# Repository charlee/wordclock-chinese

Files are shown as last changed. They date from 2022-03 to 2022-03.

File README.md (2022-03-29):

Chinese Word Clock
======================

[中文版](#汉字文字钟)

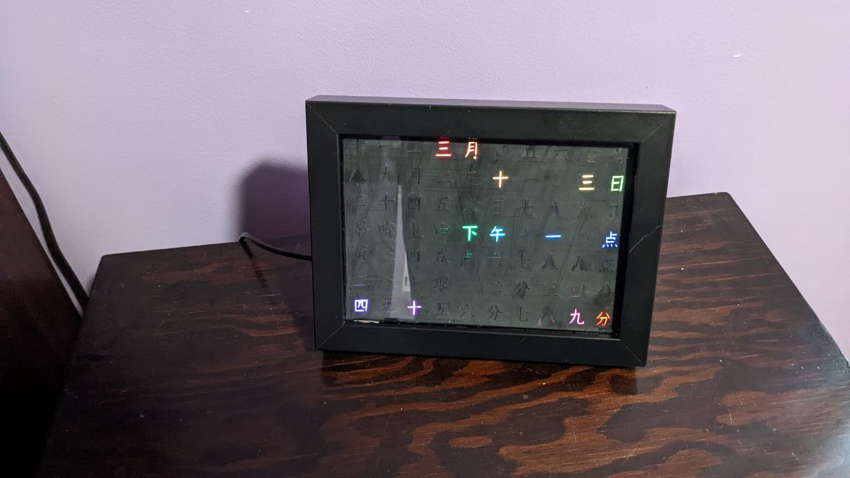
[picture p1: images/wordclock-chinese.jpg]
Chinese Word Clock


Inspired by the famous [Word Clock](https://www.instructables.com/Wordclock/),
this project created a word clock that consists of Chinese characters.
Driven by an ESP8266, this clock synchronize time from NTP servers automatically.

## Hardware

The clock itself is a 7x10 LED matrix consists of 70 WS2812b RGB LEDs,
cut from an LED strip. The microcontroller is an ESP8266 DevKit,
which provides Micro-USB interface used to power the ESP8266 and the LEDs.

### Power

WS2812b RGB consumes a lot of power. When displaying white color in full brightness,
it consumes about 60mA at 5V (20mA per R, G, B color). 
In the worst case, there are 16 LEDs being turned on (e.g. "十二月二十四日晚上十一点五十六分"),
which consumes 60mA * 16 = 960mA. 

Also, according to [the datasheet of ESP8266](https://www.espressif.com/sites/default/files/documentation/0a-esp8266ex_datasheet_en.pdf), it consumes about 170mA when using WiFi.

So the total current is about 1.2A. Therefore, a USB power adapter at least 1.5A is required.

Also note that 1.2A goes way beyond the 500mA limit that computer USB ports could provide.
When debugging / developing programs on the computer, make sure to use a small brightness.

### Frame and Case

The frame is an [IDEA RIBBA 13cm x 18cm Picture Frame](https://www.ikea.com/ca/en/p/ribba-frame-white-70378414).
This frame is inexpensive, and is thick enough to hide electronic components inside. It is a good choice for similar electronic projects.

In the [STL](STL/) folder I provided the STL files used in these project.

## Development

The program is written with Arduino. 

The whole program consists of the following parts:

- `ChineseWordMatrix.*`: convert timestamps to LED indicies.
- `EEPROMConfig.*`, `ESP8266AutoConfig.*`, `WiFiConfig.*`: provides the WiFi management functionality.
- `Animation.*`: implements the fade in/fade out/breathing animations.

汉字文字钟
============

本项目是一个汉字版本的文字钟，通过钟面上的汉字来显示时间。创意来自[Word Clock](https://www.instructables.com/Wordclock/)。
微控制器为ESP8266，因此设备支持WiFi，并且可以自动从NTP服务器同步时间。

## 硬件

钟面本身由70个 WS2812b RGB LED组成。LED来自一条RGB LED灯带。微控制器为一块ESP8266开发板，
可以通过Micro-USB为ESP8266和LED供电。

### 电源

WS2812b RGB LED本身会消耗很大电力。在以最大亮度显示白色时，一颗RGB大约产生60mA的电流（红黄蓝每种颜色各20mA）。
在最坏的情况下，会有16个LED同时亮起（例如“十二月十二四日晚上十一点五十六分”），此时产生的电流为 60mA * 16 = 960mA。

另外，根据[ESP8266的数据手册](https://www.espressif.com/sites/default/files/documentation/0a-esp8266ex_datasheet_en.pdf)，在使用WiFi时，
ESP8266会产生大约170mA的电流。

总电流约为1.2A。因此，需要使用至少1.5A的USB适配器来供电。

另外，1.2A已远远超过了电脑的USB接口能提供的500mA限制。因此在开发或调试时，务必将brightness设为一个较小的值。

### 框体和外壳

框体采用的是[宜家的RIBBA 15cm x 18cm 相框](https://www.ikea.com/ca/en/p/ribba-frame-white-70378414).
这款相框非常便宜，而且足够厚，内部可以容纳许多电子元件，非常适合类似的项目。

[STL](STL/)文件夹下提供了本项目用到的STL文件。

## 开发

程序基于Arduino。

整个程序由以下模块组成：

- `ChineseWordMatrix.*`：负责将时间戳转换成LED的序号。
- `EEPROMConfig.*`, `ESP8266AutoConfig.*`, `WiFiConfig.*`：负责WiFi管理和配置。
- `Animation.*`：用于产生渐入/渐出和呼吸效果的动画。

## License

Shield: [][cc-by-nc-sa]

This work is licensed under a
[Creative Commons Attribution-NonCommercial-ShareAlike 4.0 International License][cc-by-nc-sa].

[][cc-by-nc-sa]

[cc-by-nc-sa]: http://creativecommons.org/licenses/by-nc-sa/4.0/
[cc-by-nc-sa-image]: https://licensebuttons.net/l/by-nc-sa/4.0/88x31.png
[cc-by-nc-sa-shield]: https://img.shields.io/badge/License-CC%20BY--NC--SA%204.0-lightgrey.svg

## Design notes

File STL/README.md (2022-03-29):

STL Files
=====================

[中文版](STL文件)

This folder contains the STL files I used in this project.

- `mask.stl`: The mask with Chinese characters. I don't have a CNC carving machine so I printed it. Use a CNC to get a better result, if you have one.
  - When slicing, *flip the model* to make it facing down (to get a flat surface), then *rotate it 45 degree* (to avoid 45 degree printing marks).
  - Calibrate your flow rate to avoid any overextrusion. Overextrusion will fill the gap for the characters and lead to failure.
  - DO NOT use ironing.
  - Sand the surface with sandpapers. Use 400 => 600 => 1000 => 1500 grit to get a good result.
- `grid.stl`: The grid for blocking the LED lights.
- `case-bottom.stl` and `case-lid.stl`: The case for the ESP8266 Dev Kit.

STL文件
=========

本文件夹提供了项目中用到的STL文件。

- `mask.stl`：写有汉字的遮罩。这个遮罩用CNC雕刻机制作的效果最好，但我只有3D打印机，只能打印了。
  - 在切片前，将模型*翻转*至正面朝下（以获得平整的表面），并*旋转45度*（避免出现45度角的打印痕迹）。
  - 务必校准打印机的flow rate，避免过度挤出。过度挤出会填满汉字的缝隙，导致打印失败。
  - **不要使用ironing**。
  - 打印完毕后用砂纸打磨表面。建议采用400 => 600 => 1000 => 1500的顺序以获得较好的效果
- `grid.stl`：阻光用的格栅。
- `case-bottom.stl` 和 `case-lid.stl`：ESP8266开发板的外壳。

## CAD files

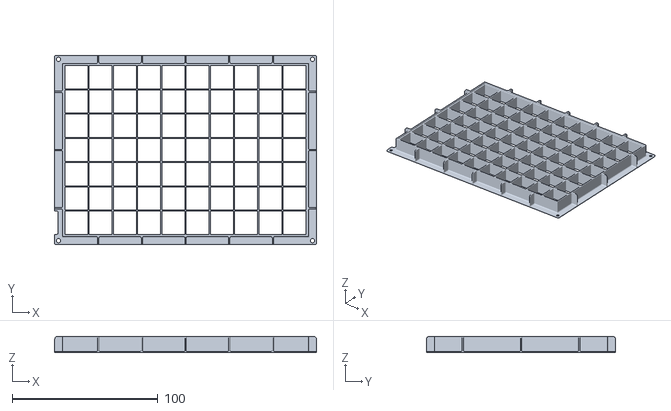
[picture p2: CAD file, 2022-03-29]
STL/grid.stl
180.0 x 130.0 x 11.2

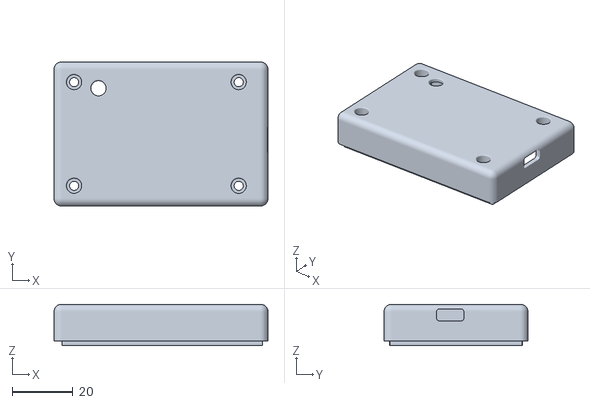
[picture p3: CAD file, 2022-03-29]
STL/case-lid.stl
70.2 x 47.2 x 13.6

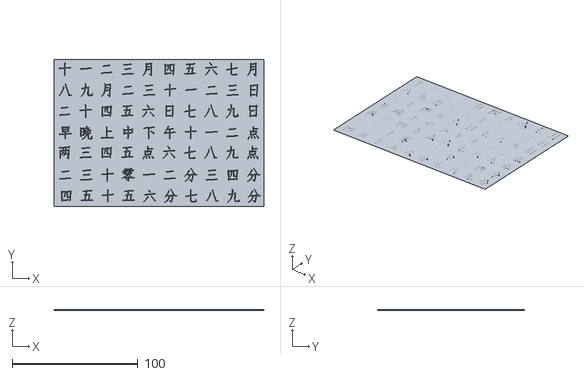
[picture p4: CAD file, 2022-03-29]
STL/mask.stl
167.0 x 117.0 x 0.6

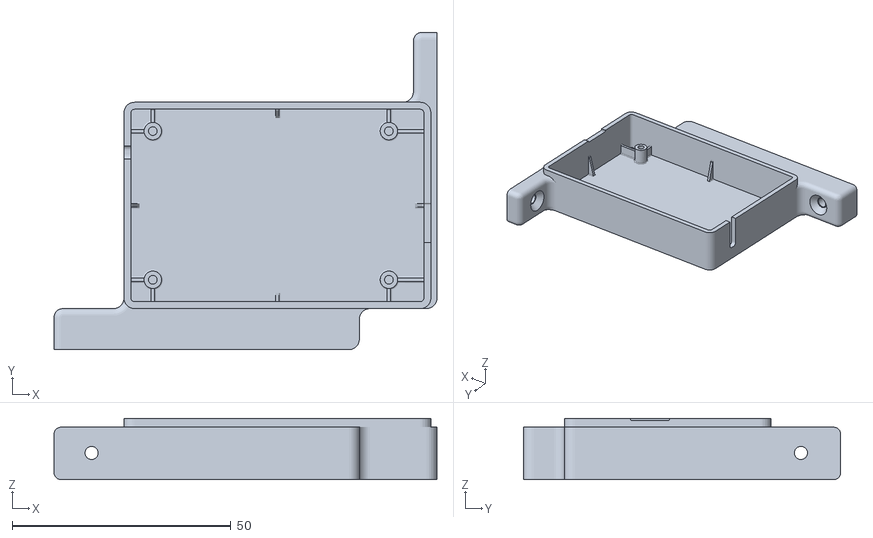
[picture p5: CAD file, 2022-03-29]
STL/case-bottom.stl
87.6 x 72.6 x 14.0

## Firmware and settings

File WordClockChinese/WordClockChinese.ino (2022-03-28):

#include <WiFiUdp.h>
#include <NTPClient.h>

#define FASTLED_ALLOW_INTERRUPTS 0

#include <FastLED.h>

#include "config.h"
#include "WiFiConfig.h"
#include "ESP8266AutoConfig.h"
#include "ChineseWordMatrix.h"
#include "Animation.h"

#define RECONFIG_PIN 5

#define DATA_PIN 4

#define COLOR_TEST 0

WiFiUDP ntpUDP;
NTPClient ntpClient(ntpUDP, NTP_SERVER, 0, 3600 * 1000);

CRGB leds[NUM_LEDS + NUM_SACRIFICE_LED];
Animation animation;

unsigned long epoch;
uint8_t led_pos[16];
int count;

unsigned long prev_epoch = 0;
int prev_count = 0;
uint8_t prev_led_pos[16] = { 99, 99, 99, 99, 99, 99, 99, 99, 99, 99, 99, 99, 99, 99, 99, 99 };

uint8_t decisec = 0;

void setup() {

  // initialize serial debug port
  Serial.begin(115200);
  Serial.println();

  // connect IO4 to GND to reconfig WiFi
  pinMode(RECONFIG_PIN, INPUT_PULLUP);

#if COLOR_TEST
#else
  int reconfig = digitalRead(RECONFIG_PIN);
  if (reconfig == LOW) {
    ESP8266AutoConfig.startAp(true);
  } else {  
    // starting WiFi
    bool connected = ESP8266AutoConfig.connectWiFi(true);
    if (connected) {

      // start NTP client
      Serial.printf("WiFi connected, init NTP client with timezone %d\n", WiFiConfig.timezone());
      ntpClient.setTimeOffset(WiFiConfig.timezone() * 3600);
      ntpClient.begin();

    }
  }
#endif

  // setup LEDs
  FastLED.setMaxPowerInVoltsAndMilliamps(5, 400);
  FastLED.setBrightness(200);
  FastLED.addLeds<NEOPIXEL, DATA_PIN>(leds, NUM_LEDS + NUM_SACRIFICE_LED);
  Serial.printf("LEDs setup done.\n");
}

int c = 0;


// the loop function runs over and over again forever
void loop() {
  ESP8266AutoConfig.poll();
  ntpClient.update();

#if COLOR_TEST
  CHSV color;
  Serial.printf("c = %d\n", c);
  Gradient *p = new Gradient(10, c);
  for (int i = 0; i < 10; i++) {
    p->getColor(i, color);
    leds[10+i] = color;
  }
  FastLED.show();
  delete p;
  c++;

  if (c == 24) c = 0;
  delay(1000);
#else

  epoch = ntpClient.getEpochTime();
  
  // update prev data only when decisec == 0
  if (epoch != prev_epoch || decisec >= 10) {
    prev_epoch = epoch;
    decisec = 0;
    animation.createAnimation(epoch);
  } else {
    decisec++;
  }

  for (int i = 0; i < NUM_LEDS; i++) {
    leds[i + NUM_SACRIFICE_LED] = animation.getColor(i, decisec);
  }

  FastLED.show();

  delay(100);
#endif
}

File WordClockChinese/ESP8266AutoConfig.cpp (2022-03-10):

#include "ESP8266AutoConfig.h"
#include "WiFiConfig.h"
#include <stdint.h>

#define XSTR(s) STR(s)
#define STR(s) #s

const char * form = "\
<form action='/connect' method='POST'>\
  <div>SSID: <input type='text' name='ssid' maxlength='" XSTR(SSID_SIZE) "'></div>\
  <div>Passphase: <input type='text' name='passphrase' maxlength='" XSTR(PASSPHRASE_SIZE) "'></div>\
  <div>Timezone: <input type='text' name='timezone' maxlength='3'></div>\
  <div><button type='submit'>Connect</button></div>\
<form>\
";


void ESP8266AutoConfigClass::handleRoot() {
  m_server->send(200, "text/html", form);
}

void ESP8266AutoConfigClass::handleConnect() {
  String argName;

  if (m_server->method() != HTTP_POST) {
    m_server->send(405, "text/plain", "Method Not Allowed");
  } else {
    for (int i = 0; i < m_server->args(); i++) {
      argName = m_server->argName(i);
      if (argName.equals("ssid")) {
        WiFiConfig.setSsid(m_server->arg(i).c_str());
      } else if (argName.equals("passphrase")) {
        WiFiConfig.setPassphrase(m_server->arg(i).c_str());
      } else if (argName.equals("timezone")) {
        WiFiConfig.setTimezone((int8_t)m_server->arg(i).toInt());
      }
    }

    if (strlen(WiFiConfig.ssid()) > 0) {
      Serial.printf("SSID=%s, passphrase=%s, timezone=%d saved.\n", WiFiConfig.ssid(), WiFiConfig.passphrase(), WiFiConfig.timezone());
      WiFiConfig.commit();

      m_server->send(200, "text/plain", "SSID and Passphrase saved.");

      if (m_isAutoMode) {
        stopAp();
      }
    } else {
      m_server->send(400, "text/html", "Empty SSID, please <a href='/'>try again</a>.");
    }
  }
}

void ESP8266AutoConfigClass::poll() {
  if (m_isApMode && m_server) {
    m_server->handleClient();
  }
}

void ESP8266AutoConfigClass::startWebServer() {
  m_server = new ESP8266WebServer(80);
  Serial.print("Starting web server for AP mode...");
  m_server->on("/", std::bind(&ESP8266AutoConfigClass::handleRoot, this));
  m_server->on("/connect", std::bind(&ESP8266AutoConfigClass::handleConnect, this));
  m_server->begin();
  Serial.println("done.");
}

void ESP8266AutoConfigClass::stopWebServer() {
  if (m_server) {
    m_server->close();
    m_server->stop();
    m_server = NULL;
  }
}

bool ESP8266AutoConfigClass::startAp(bool autoMode) {
  Serial.print("Starting AP mode...");

  bool result = WiFi.softAP("Chinese Word Clock", "");

  if (result) {
    Serial.println("ready");
    startWebServer();
    m_isApMode = true;
  } else {
    Serial.println("failed");
  }

  m_isAutoMode = autoMode;

  return result;
}

bool ESP8266AutoConfigClass::stopAp() {
  Serial.print("Stopping AP mode...");

  stopWebServer();

  bool result = WiFi.softAPdisconnect(true);
  if (result) {
    Serial.println("done");
    m_isApMode = false;
  } else {
    Serial.println("failed");
  }

  if (m_isAutoMode) {
    connectWiFi(true);
  }

  return result;
}

bool ESP8266AutoConfigClass::connectWiFi(bool autoMode) {
  int status;

  Serial.print("Reading SSID from EEPROM...");
  WiFiConfig.read();

  bool isValid = WiFiConfig.isValid();

  if (isValid) {
    Serial.printf("done, SSID = %s\n", WiFiConfig.ssid());
  } else {
    Serial.print("failed\n");
  }

  if (isValid) {
    // connect to wifi
    Serial.printf("Connecting to %s", WiFiConfig.ssid());

    WiFi.begin(WiFiConfig.ssid(), WiFiConfig.passphrase());

    status = WiFi.status();
    while (status != WL_CONNECTED && status != WL_CONNECT_FAILED && status != WL_WRONG_PASSWORD) {
      delay(500);
      Serial.print(".");
      status = WiFi.status();
    }

    if (status == WL_CONNECTED) {
      Serial.printf("connected, IP = %s\n", WiFi.localIP().toString().c_str());
      return true;
    } else {
      Serial.printf("failed\n");
    }
  }

  m_isAutoMode = autoMode;
  if (autoMode) {
    startAp(true);
  }

  return false;
}

bool ESP8266AutoConfigClass::isApMode() const {
  return m_isApMode;
}


ESP8266AutoConfigClass ESP8266AutoConfig;

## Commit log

2022-02-13 show clock leds
2022-03-10 added sacrifice led
2022-03-29 added images and stl files
    [case-bottom.stl, case-lid.stl, grid.stl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]
